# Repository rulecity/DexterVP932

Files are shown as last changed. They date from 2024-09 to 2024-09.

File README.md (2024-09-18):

# Dexter - Philips 22VP932 Adapter
A simple adapter to enable Dexter to interface with games that used the Philips 22VP932 laserdisc player.  The only two games I know of are the Atari/European versions of Dragon's Lair and Space Ace.

# Background
When I was working on Dexter, a solid-state laserdisc player replacement for laserdisc arcade games, I wanted to add support for every laserdisc player on the main PCB.
However, it became apparent that I would probably never ship the product if I waited until every player was added to the main PCB.  So I designed the DB25 interface to be expandable and hopefully support future players down the road.
This VP932 adapter is the first adapter I made that extends from Dexter's DB25 interface.  Fortunately, it works correctly.

# PCBs
I created the PCB with Eagle v7.7.0.  I have briefly tested these files on Kicad v6 and they seem to work fine.

This was a smaller project so it was a little rushed.  You may notice that there is overlapping silkscreen on the PCB and the schematic page has no proper border.

# Bill of Materials
These are the actual spreadsheets I used when ordering parts for this PCB and assembling this PCB.

# Support
If you need help having PCBs made from the source files or with any other aspect of this repository, I offer commercial support: https://www.daphne-emu.com:9443/mediawiki/index.php/CommercialSupport

--Matt Ownby

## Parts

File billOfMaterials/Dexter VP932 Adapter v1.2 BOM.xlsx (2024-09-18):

Quantity | Reference | Manufacturer | Mfg # | Distributor | Dist # | Note
SURFACE MOUNT
1 | LED1 | Kingbright Company LLC | APT3216SGC | Digi-Key | 754-1141-1-ND
5 | C1, C2, C3, C4, C5 | Samsung | CL31B104JBCNNNC | Digi-Key | 1276-1165-1-ND
1 | R1 | Panasonic | ERJ-8ENF3300V | Digi-Key | P330FCT-ND
1 | U1 | ST | ST202CDR | Digi-Key | 497-7917-2-ND
THROUGH-HOLE
1 | C6 | Panasonic | EEU-FC1A471 | Digi-Key | P10221-ND
1 | X2 | Molex | 22232021 | Digi-Key | WM4200-ND
1 | X1 | TE Connectivity / AMP | 747238-4 | Digi-Key | A2098-ND (https://www.digikey.com/product-detail/en/te-connectivity-amp-connectors/747238-4/A2098-ND/105781) | cheaper substitute is acceptable
I/O CABLE
6 |  | Molex | 2092103 | Digi-Key | WM1100-ND | I/O Pins
1 |  | Molex | 3092062 | Digi-Key | WM1328-ND | I/O Shell
POWER CABLE
4 |  | Molex | 8500114 | Digi-Key | WM1114-ND | Power pins
2 |  | Molex | 22012027 | Digi-Key | WM2011-ND | Power shell

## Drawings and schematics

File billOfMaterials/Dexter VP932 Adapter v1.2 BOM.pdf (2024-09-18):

# SURFACE MOUNT

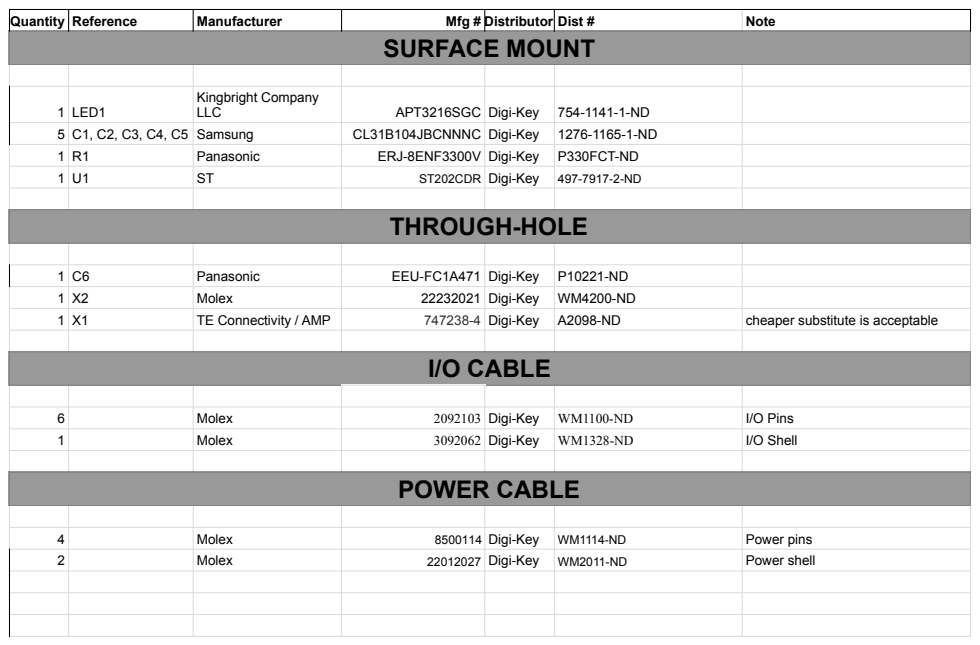
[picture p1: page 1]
Quantity; Reference; Manufacturer; Mfg # Distributor; Dist #; Note; 1 LED1; Kingbright Company; LLC; APT3216SGC; Digi-Key; 5 C1, C2, C3, C4, C5 Samsung; CL31B104JBCNNNC Digi-Key; Panasonic; ERJ-8ENF3300V; P330FCT-ND; ST202CDR; THROUGH-HOLE; EEU-FC1A471; Molex; 22232021 Digi-Key; TE Connectivity / AMP; cheaper substitute is acceptable; I/O CABLE; I/O Pins; I/O Shell; POWER CABLE; Power pins; 22012027 Digi-Key; Power shell

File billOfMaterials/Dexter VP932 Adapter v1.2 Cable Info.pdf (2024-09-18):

# I/O CABLE

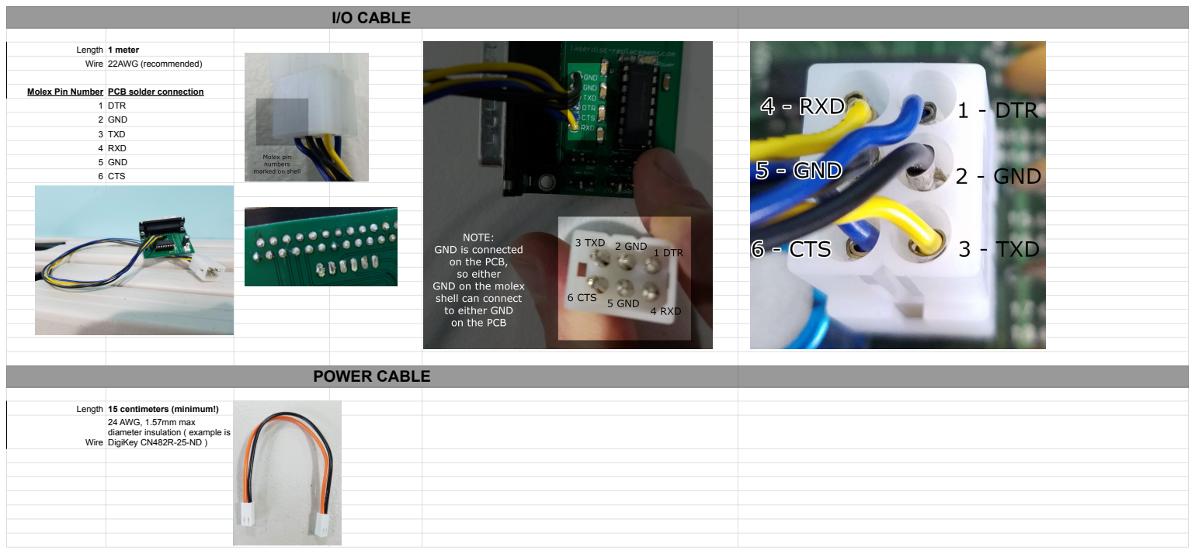
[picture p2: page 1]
1 DTR; 2 GND; 3 TXD; 4 RXD; 5 GND; 6 CTS; POWER CABLE

Length 1 meter Wire 22AWG (recommended)

Molex Pin Number PCB solder connection

Length 15 centimeters (minimum!)

24 AWG, 1.57mm max
diameter insulation ( example is
DigiKey CN482R-25-ND )
Wire

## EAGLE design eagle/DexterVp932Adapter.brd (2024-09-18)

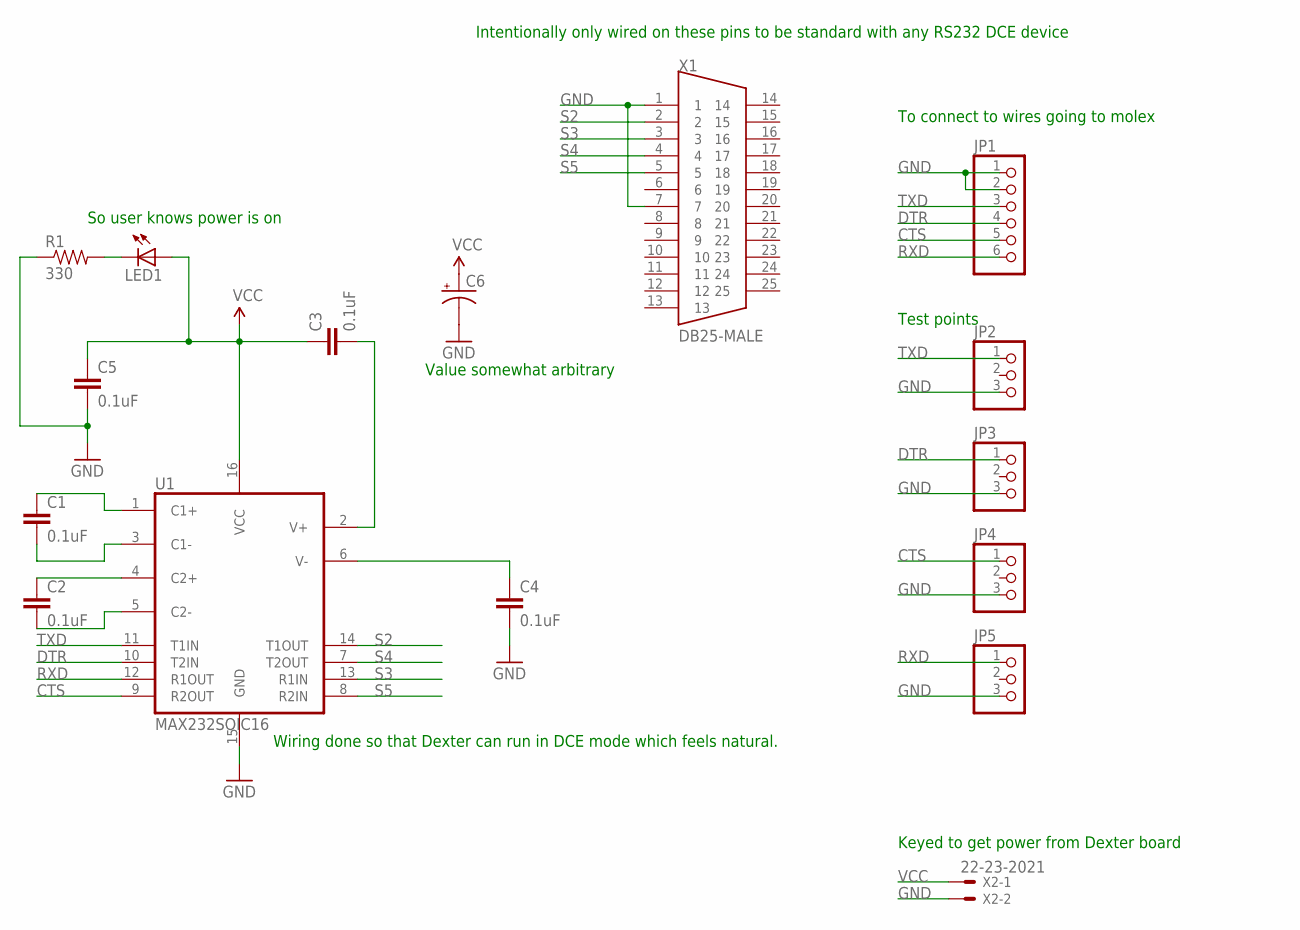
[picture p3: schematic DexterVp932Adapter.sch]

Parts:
C1, C2, C3, C4, C5: 0.1uF; 1206
C6: CAP_POLPTH2; CPOL-RADIAL-10UF-25V
JP1: PINHD-1X6; 1X06
JP2, JP3, JP4, JP5: PINHD-1X3; 1X03
LED1: LED1206; LED-1206
R1: 330; 1206
U1: MAX232SOIC16; SO016
X1: DB25-MALE
X2: 22-23-2021

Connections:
CTS: JP1.5, JP4.1, U1.9 (R2OUT)
DTR: JP1.4, JP3.1, U1.10 (T2IN)
FDFG: C2.2, U1.5 (C2-)
GND: C4.2, C5.2, C6.2 (-), JP1.1, JP1.2, JP2.3, JP3.3, JP4.3, JP5.3, R1.1, U1.15 (GND), X1.1, X1.7, X2.2
unnamed: C1.1, U1.1 (C1+)
unnamed: C1.2, U1.3 (C1-)
unnamed: C2.1, U1.4 (C2+)
unnamed: LED1.C, R1.2
unnamed: C4.1, U1.6 (V-)
unnamed: C3.2, U1.2 (V+)
RXD: JP1.6, JP5.1, U1.12 (R1OUT)
S2: U1.14 (T1OUT), X1.2
S3: U1.13 (R1IN), X1.3
S4: U1.7 (T2OUT), X1.4
S5: U1.8 (R2IN), X1.5
TXD: JP1.3, JP2.1, U1.11 (T1IN)
VCC: C3.1, C5.1, C6.1 (+), LED1.A, U1.16 (VCC), X2.1

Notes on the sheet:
Wiring done so that Dexter can run in DCE mode which feels natural.
Keyed to get power from Dexter board
Intentionally only wired on these pins to be standard with any RS232 DCE device
To connect to wires going to molex
Test points
So user knows power is on
Value somewhat arbitrary

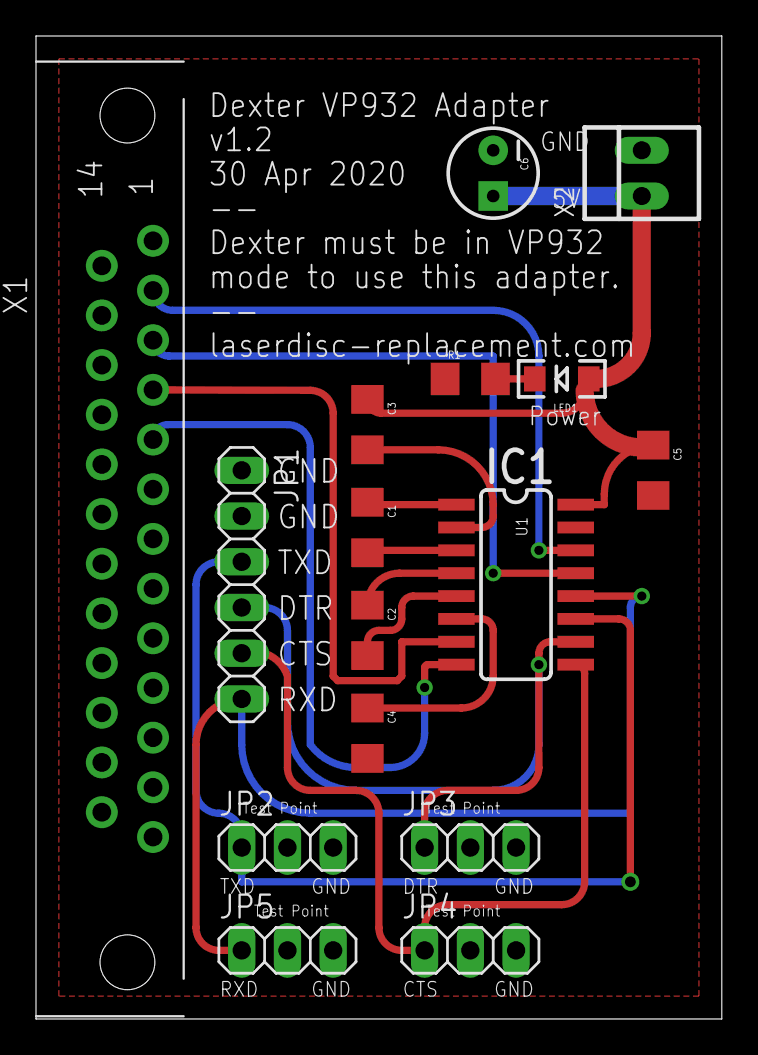
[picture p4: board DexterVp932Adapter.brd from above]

Board: 2 copper layers, 38.1 x 54.6 mm, 16 parts (0 on the bottom side), 17 nets.

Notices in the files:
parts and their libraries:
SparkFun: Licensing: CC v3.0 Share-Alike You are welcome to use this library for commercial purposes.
